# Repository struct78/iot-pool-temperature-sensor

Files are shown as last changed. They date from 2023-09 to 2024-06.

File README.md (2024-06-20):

# IOT Pool Temperature Sensor

        

This project was inspired by my children, who kept asking to go outside to check if the pool was warm or not. Which prompted some questions:

1) How warm is warm enough for everyone?
2) How cold does the pool get in winter?
3) Why are you asking me? Check the website! [canwegointhepool.com](https://canwegointhepool.com)

#### Oh hell no
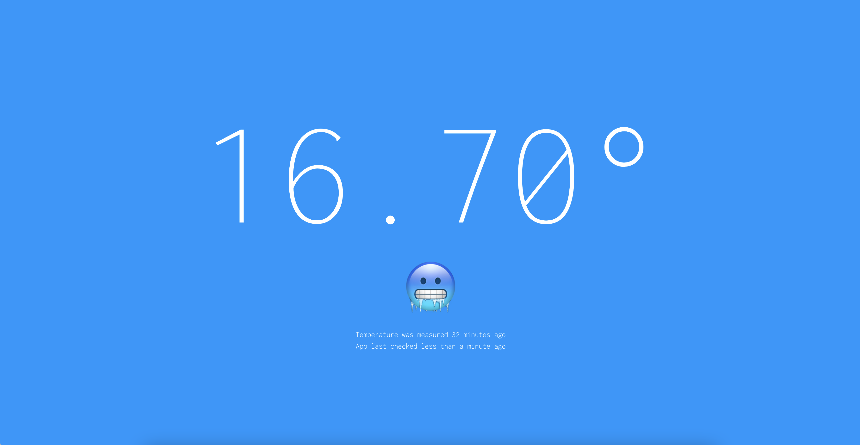
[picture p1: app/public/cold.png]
Cold


#### You can go in, I'm just going to watch
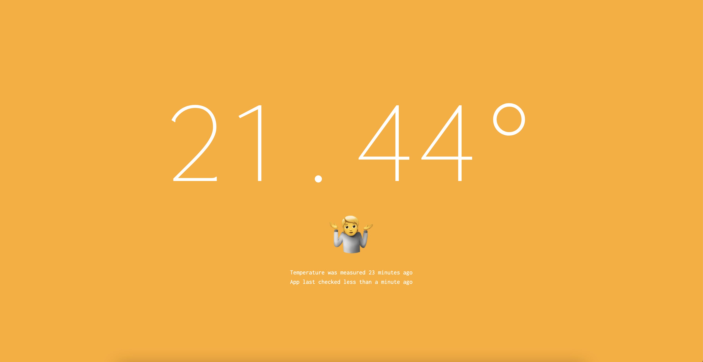
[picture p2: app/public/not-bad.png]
Not bad


#### Woohoo! Let's go!
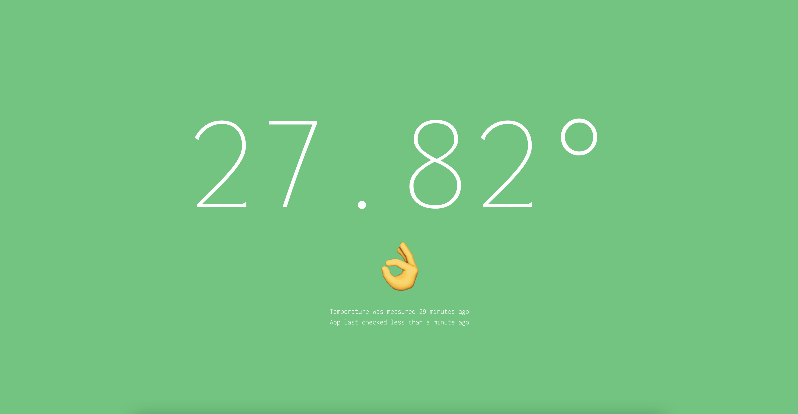
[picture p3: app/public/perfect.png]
Perfect


## How to install
The first step is to clone this repository, and update `config.json` with the domain name you want to use.

## Infrastructure
The platform is built on AWS, which collects temperature readings in a database and serves the web app. The CDK project includes:

- Route 53
- API Gateway w/ Lambda integrations (including API key for the write endpoint)
- DynamoDB

The web app is deployed using Vercel.

### Estimated Cost
The deployed AWS infrastructure, depending on your region(s) and usage, will cost about $1-2 per month.

### How to deploy & destroy

To install dependencies:
```bash
cd infrastructure
npm i
```

To deploy, first we need to build the app:
```bash
cd app
npm run build
cd ../infrastructure
```

Then run the deploy command:
```bash
npm run deploy
```

To destroy:
```bash
npm run destroy
```

## App
The web app is a simple Next.js site which pulls the latest temperature reading from the API Gateway.

To install dependencies:

```bash
cd app
npm i
```

To run:

```bash
npm run develop
```

To build:

```bash
npm run build
```

## Arduino
The code for the Arduino project is also included. You will need the following items for it to work:

| Item | Price |
-------|---------
[Arduino Uno Wifi Rev2](https://core-electronics.com.au/arduino-uno-wifi-rev2.html) | AUD$96.90
[ProtoShield + Mini Breadboard for Arduino](https://core-electronics.com.au/protoshield-mini-breadboard-for-arduino.html) | AUD$8.25
[Temperature Sensor - Waterproof (DS18B20)](https://core-electronics.com.au/temperature-sensor-waterproof-ds18b20.html) | AUD$21.13
[Flanged Weatherproof Enclosure With PG-7 Cable Glands](https://core-electronics.com.au/flanged-weatherproof-enclosure-with-pg-7-cable-glands.html) | AUD$28.10
[5mm Pitch 2-Pin Screw Terminal Block](https://core-electronics.com.au/2-pin-screw-terminal-block-5mm-pitch.html) | AUD$0.44
[POLOLU-2443 - Screw Terminal Block: 3-Pin, 5 mm Pitch, Top Entry](https://core-electronics.com.au/screw-terminal-block-3-pin-5-mm-pitch-top-entry-4-pack.html) | AUD$3.44
[Jumper wires](https://core-electronics.com.au/jumbo-jumper-wire-kit-for-solderless-breadboard-350-pcs.html) | AUD$27.50
----------------

Total Spend: AUD $185.76

### How to run
First create a `credentials.h` file.

```bash
cd arduino/iot-pool-temperature-sensor
cp credentials.h.example credentials.h
```

Update the credentials:
```c++
const char WIFI_SSID[] = "network";
const char WIFI_PASSWORD[] = "password";
const char API_GATEWAY_ENDPOINT[] = "api.{YOUR_DOMAIN}";
const int API_GATEWAY_PORT = 443;
const char API_KEY[] = "abc1234"; # Retrieve this value from Secrets Manager
```

Connect the Arduino to your computer via USB and then deploy via the Arduino IDE.

### Diagram
I've created a simple [Fritzing](https://fritzing.org) diagram which explains how to wire everything up: [Download Fritzing Diagram](https://raw.githubusercontent.com/struct78/iot-pool-temperature-sensor/master/arduino/diagram.fzz)

IOT Pool Temperature Sensor Fritzing Diagram

## Known Issues

There is a [known issue](https://github.com/arduino-libraries/WiFiNINA/issues/200) with the Arduino WiFi Rev2 and the WiFiNiNA library, whereby if you have multiple APs (wifi booster, range extenders, etc) with the same SSID, the board will often connect to the most distant AP. i.e. it is not smart enough to connect to the closest/strongest one, which leads to periodic drop outs.

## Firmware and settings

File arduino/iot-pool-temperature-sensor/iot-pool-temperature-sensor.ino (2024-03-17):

#include "credentials.h"
#include <OneWire.h> 
#include <DallasTemperature.h>
#include <WiFiNINA.h>
#include <ArduinoHttpClient.h>

#define MIN_RSSI -80
#define MAX_RSSI -50
#define NUM_BARS 7
#define INTERVAL 60000

OneWire oneWire(2); 
DallasTemperature sensors(&oneWire);
WiFiSSLClient client;

unsigned long lastMillis = 0;

// This code reboots the Arduino if we're having trouble connecting to the Wi-Fi
void(* resetFunc) (void) = 0;

void setup()
{
  Serial.begin(9600);
  sensors.begin();
  connectWiFi();
}

void loop() {
  if (WiFi.status() != WL_CONNECTED) {
    connectWiFi();
  }

  if (millis() - lastMillis > INTERVAL || lastMillis == 0) {
    lastMillis = millis();
    publishMessage();      
  }

  while (client.available()) {
    char c = client.read();
    Serial.write(c);
  }

  if (!client.connected()) {
    client.flush();
  }
}

void connectWiFi() {
  WiFi.begin(WIFI_SSID, WIFI_PASSWORD);

  Serial.print(F("Connecting to "));
  Serial.print(WIFI_SSID);
  Serial.println("");

  Serial.print("Signal strength: ");
  Serial.println(rssiBars());

  int connectionAttempts = 0;

  while (WiFi.status() != WL_CONNECTED) {
    delay(6000);
    Serial.print('.');
    connectionAttempts++;

    if (connectionAttempts > 10) {
      Serial.println("Rebooting...");
      Serial.println("");
      resetFunc();
    }
  }

  Serial.println('\n');
  Serial.println(F("Connection established!"));
  Serial.print(F("IP address:"));
  Serial.println(WiFi.localIP());
}

int rssiBars() {
  auto rssi = WiFi.RSSI();
  if (rssi <= MIN_RSSI) {
    return 0;
  } else if (rssi >= MAX_RSSI) {
    return NUM_BARS;
  } else {
    float inputRange = (MAX_RSSI - MIN_RSSI);
    float outputRange = (NUM_BARS - 1);
    return (int)( ((float)(rssi - MIN_RSSI) * outputRange / inputRange) + 0.5 );
  }
}

void publishMessage() {
  sensors.requestTemperatures();
  
  String postData = "{\"temperature\": " + String(sensors.getTempCByIndex(0)) + "}";

  Serial.println(postData);

  if (client.connectSSL(API_GATEWAY_ENDPOINT, API_GATEWAY_PORT)) {
    client.print("POST ");
    client.print(API_GATEWAY_PATH);
    client.println(" HTTP/1.1");
    client.print("Host: ");
    client.println(API_GATEWAY_ENDPOINT);
    client.println("User-Agent: Pool/1.0");
    client.println("Content-Type: application/json");
    client.print("x-api-key: ");
    client.println(API_KEY);
    client.println("Connection: close");
    client.print("Content-Length: ");
    client.println(postData.length());
    client.println();
    client.println(postData);
    client.println();
  } else {
    Serial.println("Could not send data");
  }
}

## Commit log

2023-09-17 Add -v switch
2023-09-27 Add Fritzing diagram
    [diagram.fzz]
2024-03-09 feat: Swap MySQL to DynamoDB
    I just could not get a MySQL database to work without sitting behind a very expensive VPC/NAT, so I switched back to DynamoDB. Also used a clever way of always retrieving the latest record in DynamoDB by assigning a "current" ID to a record, and updating that as well as inserting a new row whenever the /write endpoint is hit.
    This way I get a full history without all the expensive querying
2024-03-09 fix: Remove duplicate POST header
    [iot-pool-temperature-sensor.ino]
2024-03-17 fix: Change code to reliably send data
    [iot-pool-temperature-sensor.ino]
